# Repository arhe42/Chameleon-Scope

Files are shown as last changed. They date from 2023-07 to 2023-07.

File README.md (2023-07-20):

# Chameleon Scope                                                  
Welcome to the Chameleon Scope project! This open-source development repository aims to bring you a cutting-edge smart glasses solution. With a combination of Flutter for the application development, the ESP32 microcontroller for advanced functionalities, and OpenSCAD for 3D printing, Chameleon Scope is here to revolutionize the way we interact with the world.

# What is Chameleon Scope?
Chameleon Scope is a smart glasses project. It allows you to seamlessly overlay digital information onto your real-world environment, providing an immersive, recording pictures, image recognition and interactive experience. Whether you're a developer, a tech enthusiast, or simply curious about emerging technologies, Chameleon Scope offers a platform for exploration and innovation.

# How to Get Started
To get started with Chameleon Scope, follow these simple steps:
1. Clone the repository to your local machine.
2. Set up the ESP32 microcontroller with the required dependencies as mentioned in the documentation.
3. Install Flutter on your development machine if you haven't already. (https://docs.flutter.dev/deployment/android)
4. Open the Chameleon Scope application project in Flutter and ensure you have the necessary Flutter SDK version installed. Android 10 API Version 29 (https://developer.android.com/studio)
5. Build and run the application on your device or an emulator.
6. For more detailed instructions and guidelines, please refer to the project's documentation.
7. Additionally, a comprehensive handbook detailing the step-by-step process of soldering the battery to the ESP32 is available in a separate file for your reference.

# For Your Information
The Google-ML kit was used for image recognition, as Tensor Flow does not contain any documentation for Dart and OpenCV only offers image manipulation, greyscale and filter, which is not suitable for the project.

The default SSID for the ESP32-Hotspot is "Chameleon Scope", the password is the same: "Chameleon Scope".

# Contributing
We welcome contributions from the community to help make Chameleon Scope even better. If you're interested in contributing, please review our contribution guidelines outlined in the repository. You can contribute by reporting issues, suggesting new features, or submitting pull requests.

# Community and Support
Join our vibrant community of developers, enthusiasts, and contributors! If you have any questions, ideas, or feedback, feel free to reach out to us through klaus.knopper@hs-kl.de.

Let's shape the future of smart glasses together with Chameleon Scope! Happy coding and exploring the realms of augmented reality!

# Placeholder for future implementation (dummies)





# Credits
Thank you to 
[Eric N / ThatProject](https://github.com/0015/ThatProject/tree/master/ESP32CAM_Projects/ESP32_CAM_Dashcam_FLUTTER/ESP32_CAM_WEBSOCKET_SERVER) for providing the base code for the ESP32CAM.

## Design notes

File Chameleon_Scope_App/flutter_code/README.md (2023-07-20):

# Chameleon Scope Flutter Application

This is the neccessary code to get started with the Chameleon Scope Mobile Application, wether you want to just use the product or start contributing towards the project!

## Getting Started

This code provides an Object Classification show case-module, a few dummy modules for ocr, camera-input, face-recognition and audio-recording as well as modules to toggle notifications and display a video on the Chameleon Scope Glasses.

A few resources to get you started if this is your first Flutter project:

- [Lab: Write your first Flutter app](https://docs.flutter.dev/get-started/codelab)
- [Cookbook: Useful Flutter samples](https://docs.flutter.dev/cookbook)

For help getting started with Flutter development, view the
[online documentation](https://docs.flutter.dev/), which offers tutorials,
samples, guidance on mobile development, and a full API reference.

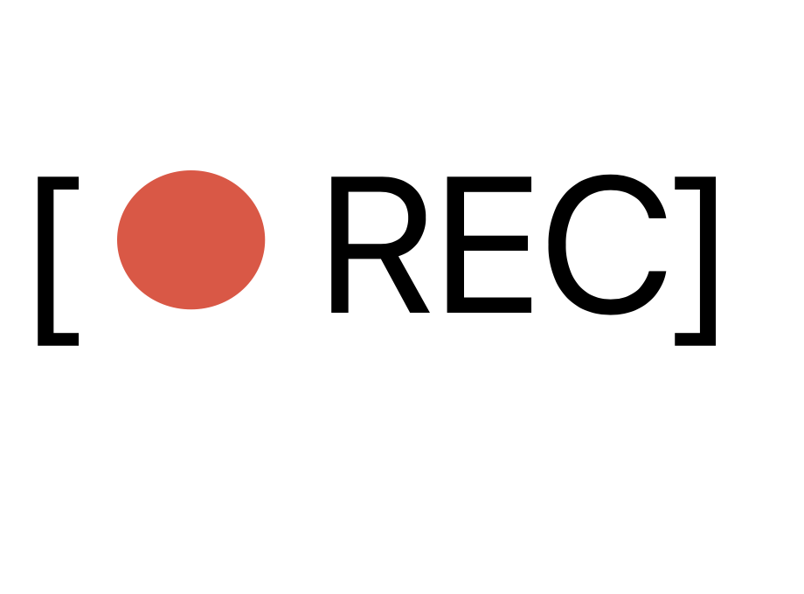
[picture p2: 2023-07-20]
Chameleon_Scope_App/flutter_code/assets/images/LiveRecord.png

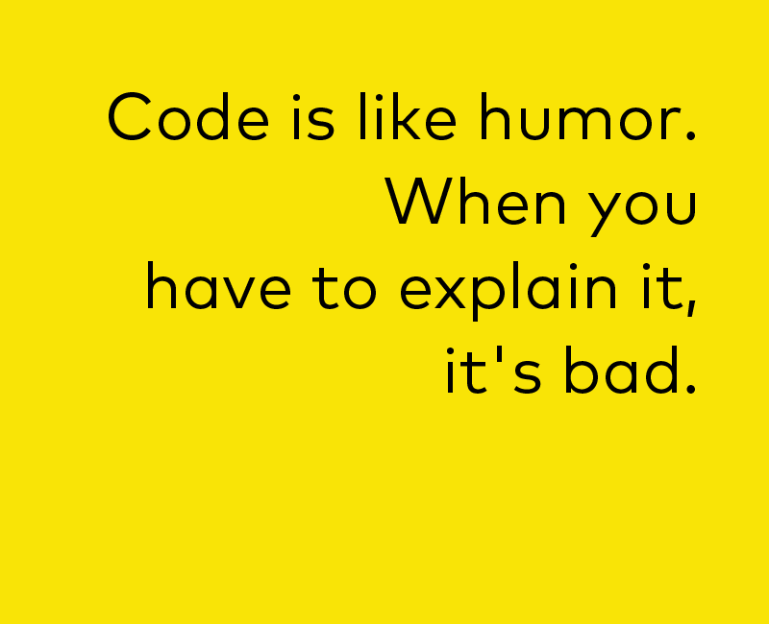
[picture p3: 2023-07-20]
Chameleon_Scope_App/flutter_code/assets/images/muster.png

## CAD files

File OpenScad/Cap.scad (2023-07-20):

//Option_1
//Plattform
translate( [40,80,15.9] ) cube([19.25,71.5-1,2.2], true, $fn=100);

difference(){
    rotate(-90,[50,0,0]) translate( [47,-14,88.5] ) cylinder (h = 3.75, r=2.25, $fn=100);
    rotate(-90,[50,0,0]) translate( [47,-14,88.25] ) cylinder (h = 8, r=0.8, $fn=100);
    translate( [48,90,15.5] ) cube([3,5,4], true);
}

//Fixation
difference(){
    rotate(-90,[50,0,0]) translate( [47,-14,68.5] ) cylinder (h = 3.75, r=2.25, $fn=100);
    rotate(-90,[50,0,0]) translate( [47,-14,68.25] ) cylinder (h = 8, r=0.8, $fn=100);
    translate( [48,70,15.5] ) cube([3,5,4], true);
}

//Option_2
//Plattform
translate( [60,80,15.9] ) cube([19.25,71.5-1,2.2], true, $fn=100);

//Fixation
translate( [68.75,90.5,14] ) cube([1.5,3,3], true);
translate( [68.75,70.5,14] ) cube([1.5,3,3], true);

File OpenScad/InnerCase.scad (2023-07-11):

//Variables:
//Case
gBreite= 21;
gLaenge=72;
gHoehe=30;
gTX=40;
gTY=80;

//Inside
iBreite=gBreite-0.5;
iLaenge=gLaenge-0.5;
iHoehe=gHoehe+2;
iTX=gTX;
iTY=gTY;

//Camera
kRadius=4.2;
kTranslateX=37;

//Lamp
lRadius=4;

//LED
LEDtranslateX=30;
LEDtranslateY=45;
LEDRadius=1;

//Cap
dBreite=gBreite-5;
dLaenge=gLaenge-5;
dHoehe=2;
dTX=40;
dTY=80;
dTZ=15;

//To Opening
oeBreite=5;
oeLaenge=10;
oeHoehe=10;
oeTX=25;
oeTY=80;
oeTZ=19;

//Magnet
mBreite=4;
mLaenge=10;
mHoehe=1.5;
mTX=29.5;
mTY=80;
mTZ=14;

//Holding 1&2
h1Breite=4;
h1Laenge=8;
h1Hoehe=1;
h1TX=48.75;
h1TY=90;
h1TZ=14;

h2Breite=4;
h2Laenge=8;
h2Hoehe=1;
h2TX=48.75;
h2TY=70;
h2TZ=14;

//Gap Holding
aBreite=2.5;
aLaenge=5.5;
aHoehe=3;
aTX=48.8;
a1TY=90;
aTZ=14;
a2TY=70;


difference(){
    //Case mit Rundung
    //Variante mit 600mAh-Akku
    minkowski(){
        translate( [gTX,gTY,0] ) cube([gBreite,gLaenge,gHoehe], true);
       sphere(2, $fn=50);
    }
    
     //Inside
    translate( [iTX,iTY,2] ) cube([iBreite,iLaenge,iHoehe+5], true, $fn=100);
    
    //Camera
    rotate(-90,[50,0,0]) translate( [kTranslateX,0,20] ) cylinder (h = 40, r=kRadius, $fn=100);
    
    //LED
    rotate(-90,[50,0,0]) translate( [LEDtranslateX,LEDtranslateY,20] ) cylinder (h = 10, r=LEDRadius, $fn=100);
    
    //For the Cap
    translate( [dTX,dTY,dTZ] ) cube([dBreite,dLaenge,dHoehe], true);
    
    //Gap to open
    translate( [oeTX,oeTY,oeTZ] ) cube([oeBreite+10,oeLaenge,oeHoehe], true);
    
     //USB
    translate( [40,116,0] ) cube([11.5,6,6.5], true);
    
    //ON_OFF
    translate( [40,116,-10] ) cube([6.4,5,3.4], true);
}

//Magnet
difference(){
    translate( [mTX,mTY,mTZ] ) cube([mBreite,mLaenge,mHoehe], true);
    
    translate( [mTX,mTY,mTZ+1] ) cylinder (h = 1, r=4.5, $fn=100);
}

//Holding to open
difference(){
    translate( [h1TX,h1TY,h1TZ] ) cube([h1Breite,h1Laenge,h1Hoehe], true);
    
    translate( [aTX,a1TY,aTZ] ) cube([aBreite,aLaenge,aHoehe], true);
}
difference(){
    translate( [h2TX, h2TY, h2TZ] ) cube([h2Breite,h2Laenge,h2Hoehe], true);
    
    translate( [aTX,a2TY,aTZ] ) cube([aBreite,aLaenge,aHoehe], true);
}

//ToGetOut
difference(){
    translate( [40,119,10] ) cube([8,3.5,1.5], true);
    translate( [40,119,10] ) cube([6.5,2,2.5], true);
}    

//Micro-USB
//Right
translate( [32.5,103.5,0.5] ) cube([2.5,25,1.25], true);
translate( [30,103.15,1.9] ) cube([2.5,25.5,4], true);
//Left
translate( [47.5,103.5,0.5] ) cube([2.5,25,1.25], true);
translate( [50,103.15,1.9] ) cube([2.5,25.5,4], true);
//Back
translate( [40,91.5,1.4] ) cube([17.7,2.2,3], true);

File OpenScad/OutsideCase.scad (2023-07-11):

gBreite= 21;
gLaenge=72;
gHoehe=30;
gTX=40;
gTY=80;

//Camera
kRadius=4.2;
kTranslateX=37;

difference(){
    minkowski(){
        translate( [gTX,gTY,0] ) cube([gBreite+3,gLaenge+3,gHoehe+3], true);
       sphere(2, $fn=50);
    }
    
    //Camera
    rotate(-90,[50,0,0]) translate( [kTranslateX,0,20] ) cylinder (h = 40, r=kRadius, $fn=100);
    
    minkowski(){
        translate( [gTX,gTY,0] ) cube([gBreite+1,gLaenge+1,gHoehe+1], true);
       sphere(2, $fn=50);
    }
    
    minkowski(){
        translate( [gTX,gTY+10,0] ) cube([gBreite+1,gLaenge+1,gHoehe+1], true);
       sphere(2, $fn=50);
    }
}

//Fixation
difference(){
    rotate(-90,[50,0,0]) translate( [58,-5,40.5] ) cylinder (h = 77, r=6.5, $fn=100);
    rotate(-90,[50,0,0]) translate( [58,-5,38] ) cylinder (h = 85, r=3.5, $fn=100);
    translate( [65,80,5] ) cube([10,80,1], true);
    
    minkowski(){
        translate( [gTX,gTY,0] ) cube([gBreite+1,gLaenge+1,gHoehe+1], true);
       sphere(2, $fn=50);
    }
    
    minkowski(){
        translate( [gTX,gTY+10,0] ) cube([gBreite+1,gLaenge+1,gHoehe+1], true);
       sphere(2, $fn=50);
    }
}

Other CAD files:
OpenScad/D2R Chameleon Scope/D2R Components.scad

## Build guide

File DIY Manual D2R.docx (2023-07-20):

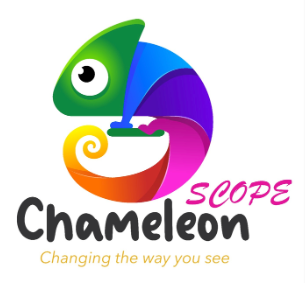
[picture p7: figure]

# DIY Manual D2R

This manual refers only to the D2R (Digital to Real) part of the Chameleon Scope project. For the R2D you find a separate manual in the repository.

# Required components

- ESP32 NodeMCU Module WROOM32
- Adafruit 1.14” 249X135 Color TFT Display
- Durovis Essentials Lens Set 2 (37mm) - 2 biconvex PMMA lenses for Virtual Reality Headsets
- EEMB Lithium Polymer Battery 3,7 V 250mAh 502030 rechargeable Lipo battery with JST connection for VXI Blue Parrott
- VUNIVERSUM 10 Pairs 2.0 PH 2Pin Premium Mini Micro JST jack incl. 15cm 26AWG silicon LiPo battery charger cable
- Aokoda CXT-405 4 CH USB 1S LiPo/LiHV Charger JST-PH 2,0 mm mCPX
- Semitransparent glass: VORCOOL Head Up Display (as projection surface)
- 3D printer and PLA filament (TPU also works) for the case
- 2 Clamps to fix the case to your chosen glasses (you should use this ones (https://www.amazon.de/Dioche-Leselicht-Brillenlampe-Angelger%C3%A4t-Wartung/dp/B07JHQP385) and remove the light spots, if you don’t want to modify the case)

# How to mount D2R part of Chameleon Scope

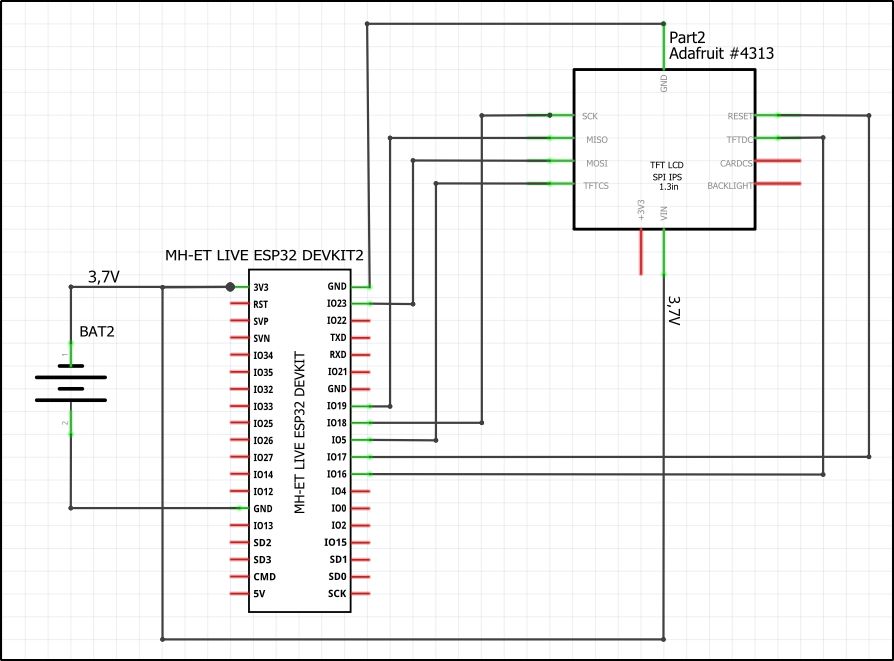
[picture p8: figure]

# Architecture

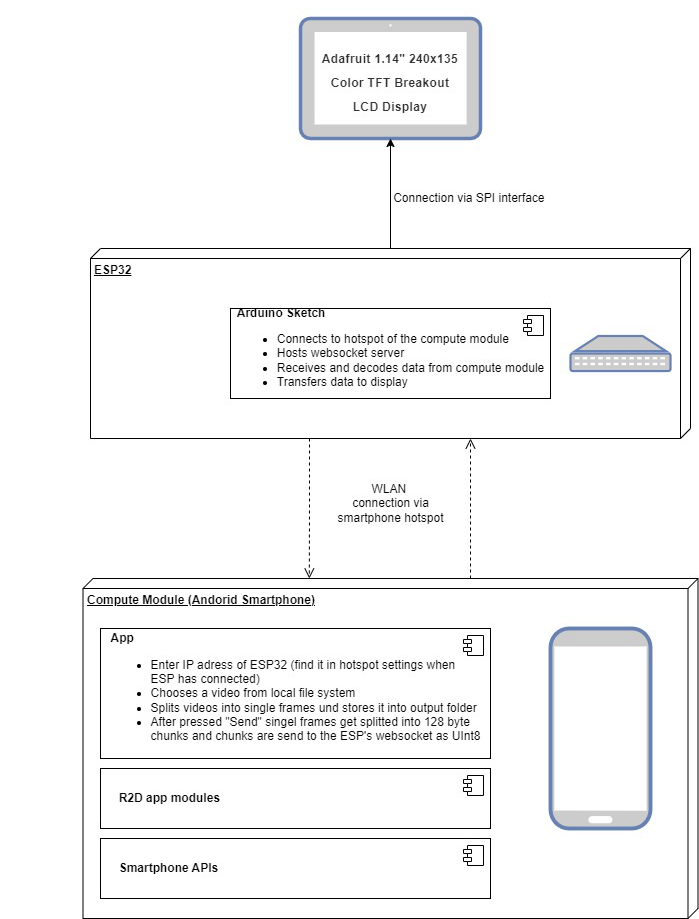
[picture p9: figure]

# Functionality

We planned to implement the following functionality:

- Select videos from local file system of your smartphone and stream them on display of Chameleon Scope, maybe even stream other videos you play on your device (like YouTube etc.).
- Show information like time, weather dates, push notifications, incoming calls and battery level in display of Chameleon Scope. In the menu of your smartphone app you can navigate to a functionality page, where you can activate or deactivate this general info.
- Interaction with retrieved data from R2D module, like the name of a person that has been recognized by face detection.
- More to come, for example AR games…

# Outstanding problems

## Video streaming

By now you can only choose a video from your local file system. Streaming of other videos is not implemented yet. We also have the problem that the streamed videos do not run fluently, as a result of the algorithm, that converts videos into single frames, then discards every second frame, and the remained ones get split into chunks to send them via UInt8List to the web socket server on ESP32. These steps are necessary, because memory of ESP32 is not able to handle larger data streams. Furthermore there is no audio output, because you have to split the same way you split the video and after that you give it to smartphone audio output. Until now, we didn’t find a way to solve this problems.

## Basic Information

The information activated on your smartphone app are not displayed on display. The functionality page is only a mockup. Only reaction to push notifications is implemented.

## AR Games

We didn’t start developing AR game enablement…

# Code assignments

You can find the Arduino Sketch for D2R ESP32 in the repository by following the path Chameleon_Scope_App/ESP_D2R/esp32websocket_d2r.ino

The flutter app parts of D2R you can find by following the following paths

- Chameleon_Scope_App/flutter_code/VideoWidget.dart for video streaming page
- Chameleon_Scope_App/flutter_code/websocket_service.dart for functionality of sending video streams
- Chameleon_Scope_App/FunctionSettingsWidget.dart for functionality settings page
- Chameleon_Scope_App/notification_service.dart for streaming push notifications

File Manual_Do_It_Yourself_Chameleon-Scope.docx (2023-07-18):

# Manual Do it yourself Chameleon Scope

## Required material

To create the R2D part of the Chameleon Scope you need the following parts:

- Camera module ESP32-CAM
- 400mAh LiPo battery 3.7V
- 3D printer and filament (TPU and PLA) for the case
- Battery 5V booster module
- Camera extension
- Cable for soldering
- I/O switch

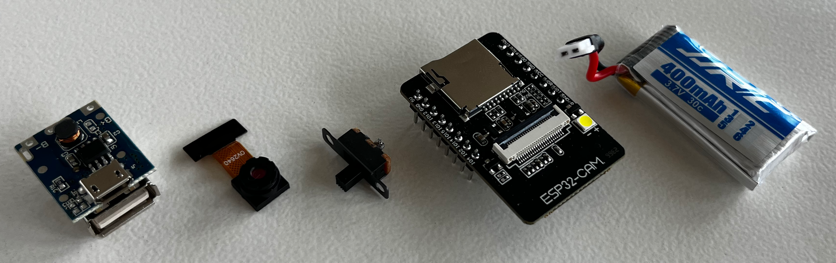
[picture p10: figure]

## Soldering

The ESP32-CAM requires 5V, while the LiPo battery transfers 3.7V voltage. To transform the voltage, it needs a booster module in between. One advantage of the booster module is that it has an integrated USB-C interface, which allows the ESP32 to be charged via the booster module. With the help of this circuit diagram, the soldering is carried out and explained step by step.

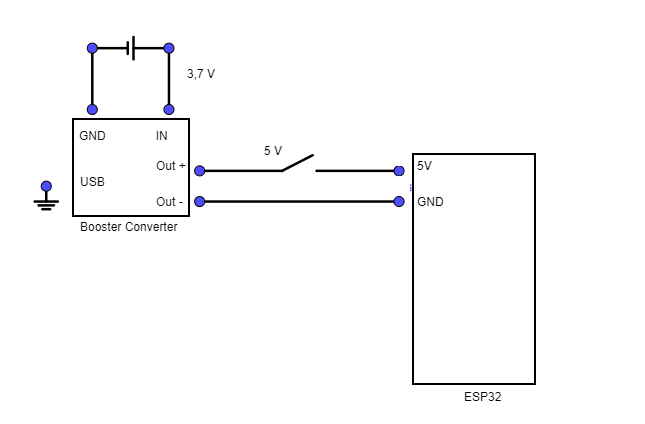
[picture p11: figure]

Step 1: Soldering the battery to the booster module

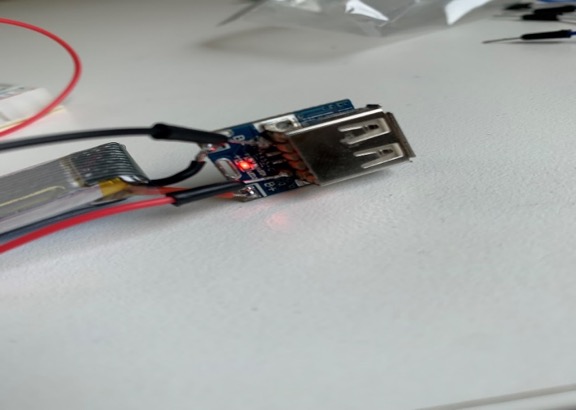
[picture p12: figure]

| 1. Start with the battery and solder its positive terminal to the B+ surface. 2. Solder the negative terminal of the battery to the B- surface. 3. Take the black cable and solder it to the outermost pin on the B side (blue marking). 4. Take the red cable and solder it to the outermost pin on the B+ side (red marking).

Step 2: Soldering the cables coming from the booster module to the switch

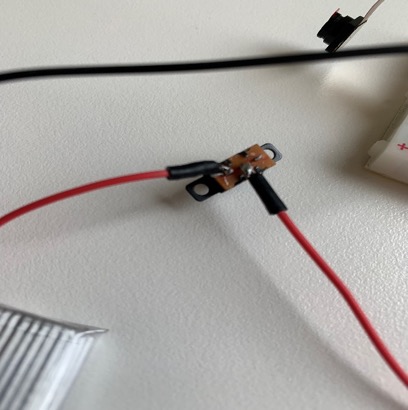
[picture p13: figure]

| 1. Begin at the booster module. 2. Solder the power supply (red cable) to the outer pin of the switch. 3. Solder another power supply (red cable) to the middle pin of the switch. 4. Connect the cable from the middle pin of the switch to the 5V pin of the microcontroller. 5. From the booster module, solder the earth (black cable) directly to the GND pin of the microcontroller, located below the 5V pin. 6. This creates a circuit that can be interrupted by the switch.

## Runtime

Runtime Microcontroller

Battery: 400 mAh LiPo Battery– 3,7 V

Booster Modul: 5V

Battery power

400 mAh * 5V

= 0,4 *5

= 2 Wh (2 Watt per hour)

Active Camera

P = 140 mW

P = 0,14 W

Runtime = 2 Wh / 0,14 W

Runtime = 14 Hours

Active flashlight

i = 0,31 A

P = 5V * 0,31 A

P = 1,55 W

Runtime = 2 Wh / 1,55 W

Runtime = 1,29 h = 1 hour 18 minutes

## IT-Architecture

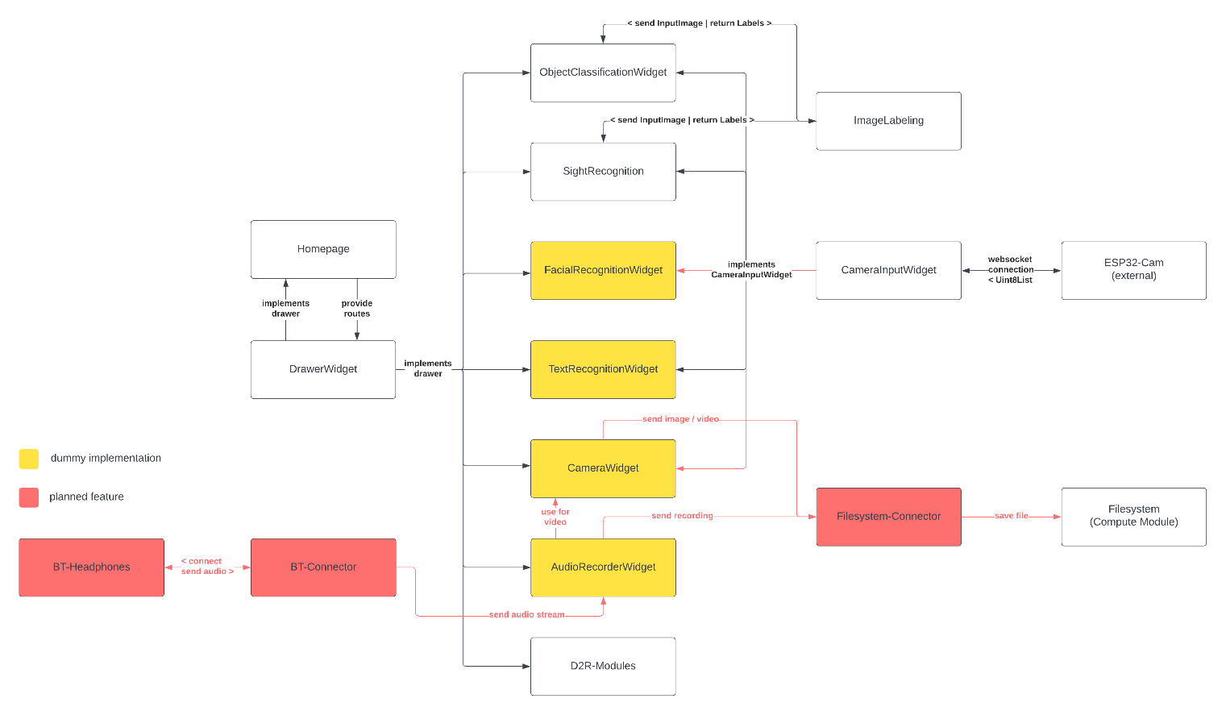
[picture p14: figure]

## 3D-Case explanation

Inner Case:

- Variables: Dimensions and translations defined.
- Code structure: Uses difference() and cube() functions.
- Case: Outer case created with cube() function.
- Inside: Interior space created with cube() function.
- Camera: Cylindrical camera object created with cylinder() function.
- LED: Cylindrical LED object created with cylinder() function.
- Cap: Cap created with cube() function.
- Gap to open: Gap for opening case created with cube() function.
- Magnet: Magnet created with cube() function.
- Holding to open: Holding structures and gap holding objects created with cube() function.

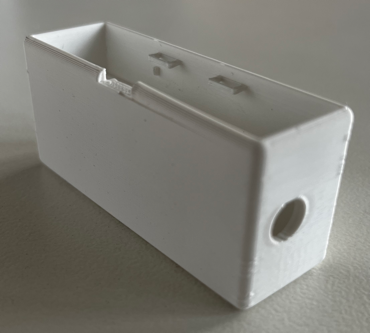
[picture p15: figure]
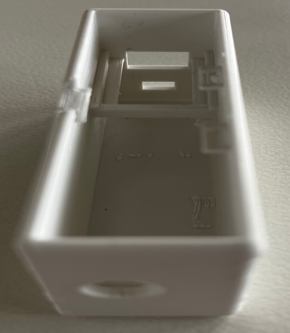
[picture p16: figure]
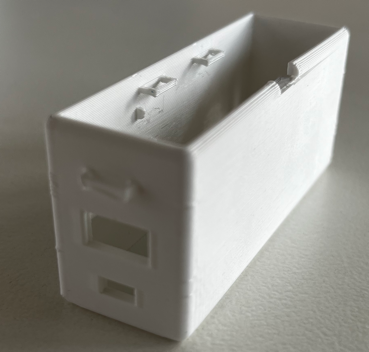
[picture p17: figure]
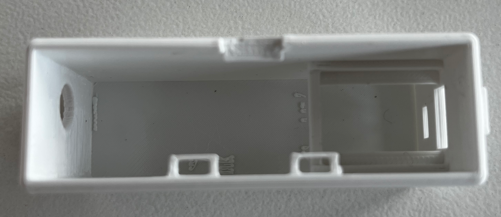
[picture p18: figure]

Outside-Case:

- Variables: Case dimensions and translations defined.
- Code structure: Uses difference() and minkowski() functions.
- Camera: Camera object created with cylinder() function.
- Case: Outer case created with cube() function.
- Additional Components: Spheres and fixation objects created with minkowski(), cylinder(), and cube() functions.
- Fixation: Fixation objects created with cylinder() and cube() functions.

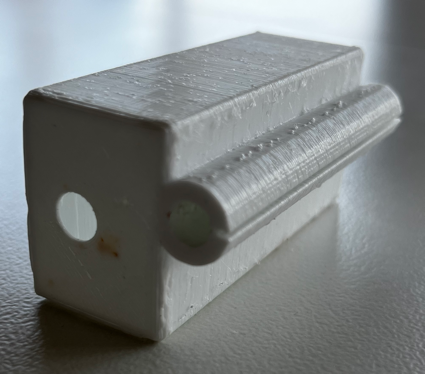
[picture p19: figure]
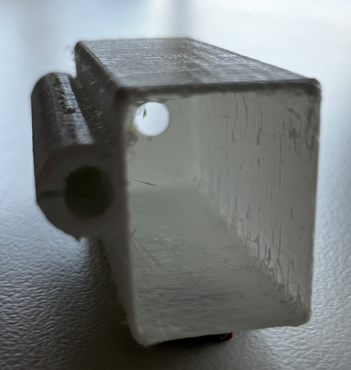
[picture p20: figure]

Cap:

- Translation and Cube: Cube created with cube() function.
- Plattform: Cylindrical and cubic objects created with cylinder() and cube() functions.
- Fixation: Cylindrical and cubic objects created with cylinder() and cube() functions

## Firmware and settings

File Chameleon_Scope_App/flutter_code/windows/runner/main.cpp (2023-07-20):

#include <flutter/dart_project.h>
#include <flutter/flutter_view_controller.h>
#include <windows.h>

#include "flutter_window.h"
#include "utils.h"

int APIENTRY wWinMain(_In_ HINSTANCE instance, _In_opt_ HINSTANCE prev,
                      _In_ wchar_t *command_line, _In_ int show_command) {
  // Attach to console when present (e.g., 'flutter run') or create a
  // new console when running with a debugger.
  if (!::AttachConsole(ATTACH_PARENT_PROCESS) && ::IsDebuggerPresent()) {
    CreateAndAttachConsole();
  }

  // Initialize COM, so that it is available for use in the library and/or
  // plugins.
  ::CoInitializeEx(nullptr, COINIT_APARTMENTTHREADED);

  flutter::DartProject project(L"data");

  std::vector<std::string> command_line_arguments =
      GetCommandLineArguments();

  project.set_dart_entrypoint_arguments(std::move(command_line_arguments));

  FlutterWindow window(project);
  Win32Window::Point origin(10, 10);
  Win32Window::Size size(1280, 720);
  if (!window.Create(L"r2d", origin, size)) {
    return EXIT_FAILURE;
  }
  window.SetQuitOnClose(true);

  ::MSG msg;
  while (::GetMessage(&msg, nullptr, 0, 0)) {
    ::TranslateMessage(&msg);
    ::DispatchMessage(&msg);
  }

  ::CoUninitialize();
  return EXIT_SUCCESS;
}

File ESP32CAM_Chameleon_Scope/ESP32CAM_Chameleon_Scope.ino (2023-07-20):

#include <ArduinoWebsockets.h>

#include "esp_camera.h"
#include <WiFi.h>
#include <WebSocketsServer.h>

#define CAMERA_MODEL_AI_THINKER
#include "camera_pins.h"

WebSocketsServer webSocket = WebSocketsServer(8888);

const char* ssid = "Chameleon Scope";
const char* password = ssid;

bool isClientConnected;

void webSocketEvent(uint8_t num, WStype_t type, uint8_t * payload, size_t length) {

    switch(type) {
        case WStype_DISCONNECTED:
            Serial.println("Disconnected!");
            break;
        case WStype_CONNECTED:
            {
                IPAddress ip = webSocket.remoteIP(num);
                Serial.print("Connected IP address:");
                Serial.println(ip);
                isClientConnected = true;
            }
            break;
    case WStype_TEXT:
    case WStype_BIN:
    case WStype_ERROR:      
    case WStype_FRAGMENT_TEXT_START:
    case WStype_FRAGMENT_BIN_START:
    case WStype_FRAGMENT:
    case WStype_FRAGMENT_FIN:
      break;
    }

}

void setup() {
  Serial.begin(115200);
  Serial.setDebugOutput(true);
  Serial.println();

  camera_config_t config;
  config.ledc_channel = LEDC_CHANNEL_0;
  config.ledc_timer = LEDC_TIMER_0;
  config.pin_d0 = Y2_GPIO_NUM;
  config.pin_d1 = Y3_GPIO_NUM;
  config.pin_d2 = Y4_GPIO_NUM;
  config.pin_d3 = Y5_GPIO_NUM;
  config.pin_d4 = Y6_GPIO_NUM;
  config.pin_d5 = Y7_GPIO_NUM;
  config.pin_d6 = Y8_GPIO_NUM;
  config.pin_d7 = Y9_GPIO_NUM;
  config.pin_xclk = XCLK_GPIO_NUM;
  config.pin_pclk = PCLK_GPIO_NUM;
  config.pin_vsync = VSYNC_GPIO_NUM;
  config.pin_href = HREF_GPIO_NUM;
  config.pin_sscb_sda = SIOD_GPIO_NUM;
  config.pin_sscb_scl = SIOC_GPIO_NUM;
  config.pin_pwdn = PWDN_GPIO_NUM;
  config.pin_reset = RESET_GPIO_NUM;
  config.xclk_freq_hz = 20000000;
  config.pixel_format = PIXFORMAT_JPEG;
  config.frame_size = FRAMESIZE_VGA;
  config.jpeg_quality = 20;
  config.fb_count = 2;


  // camera init
  esp_err_t err = esp_camera_init(&config);
  if (err != ESP_OK) {
    Serial.printf("Camera init failed with error 0x%x", err);
    return;
  }

  delay(1000);
  WiFi.softAP(ssid, password);
  IPAddress IP = WiFi.softAPIP();
  Serial.print("AP IP address: ");
  Serial.println(IP);
  webSocket.begin();
  webSocket.onEvent(webSocketEvent);
}

void loop() {
  webSocket.loop();
  if(isClientConnected){
    camera_fb_t *fb = NULL;
    esp_err_t res = ESP_OK;
    fb = esp_camera_fb_get();
    if(!fb){
      Serial.println("Camera capture failed");
      esp_camera_fb_return(fb);
      return;
    }
  
    size_t fb_len = 0;
    if(fb->format != PIXFORMAT_JPEG){
      Serial.println("Non-JPEG data not implemented");
      return;
    }
  
    webSocket.broadcastBIN((const uint8_t*) fb->buf, fb->len);
    Serial.println("image sent");
    esp_camera_fb_return(fb);    
  }
  
}

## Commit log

2023-07-11 OpenScad - Folder
    Files for the 3D-Print
    [Cap.scad, InnerCase.scad, OutsideCase.scad]
2023-07-15 added Gehäuse ASE
    [Gehäuse ASE.scad]
2023-07-18 Added Folder
    [Gehäuse ASE.scad]
2023-07-19 Update and rename Chameleon Scope R2D Variante 1.scad to Chameleon Scope D2R Variante 1.scad
    [Chameleon Scope D2R Variante 1.scad]
2023-07-20 Added ESP32CAM Code
    Initial Upload of ESP32CAM sketch.
2023-07-20 Update Cap.scad
    Two Options for the Cap
    [Cap.scad]
2023-07-20 Deleted for smaller case
    [Cahmeoeon Scope D2R Variante 2.scad]
2023-07-20 Deleted for smaller case design
    [Chameleon Scope D2R Variante 1.scad]
2023-07-20 File with final D2R case design and comments for open source community
    [D2R Components.scad]
2023-07-20 added esp32 d2r
